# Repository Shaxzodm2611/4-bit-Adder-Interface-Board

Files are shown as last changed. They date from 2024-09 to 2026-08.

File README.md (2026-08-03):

# 4-bit Adder Interface Board

> **AI-generated README**: This README was generated with AI from the repository contents and may contain mistakes or omissions. Please verify hardware details, part numbers, and wiring against the KiCad source files before using it as authoritative documentation.

## Overview

This repository contains KiCad design files for a custom PCB titled **4 Bit - Seven Seg Interface**. The project appears to be a discrete-logic interface board built around a 4-bit adder and related support circuitry, intended to drive or interface with a seven-segment display.

The repository description indicates it is:

> “A custom PCB designed to mimic the function of a CPU. Entirely made from discrete logic ICs.”

## What is in the repository

The project is organized as a KiCad hardware design with schematic sheets and board/layout files, including:

- **PCB layout**: `4 Bit - Seven Seg Interface.kicad_pcb`
- **KiCad project**: `4 Bit - Seven Seg Interface.kicad_pro`
- **Main schematic**: `4 Bit - Seven Seg Interface.kicad_sch`
- **Supporting schematics**:
  - `Adders.kicad_sch`
  - `Registers.kicad_sch`
  - `Decoder.kicad_sch`
  - `Hex.kicad_sch`
  - `A.kicad_sch`
  - `C&D.kicad_sch`
  - `G.kicad_sch`
  - `555Timer.kicad_sch`
  - `untitled.kicad_sch`
- **Footprint libraries**:
  - `Components.pretty/`
  - `15000LED.pretty/`
- **Backup files**:
  - `4 Bit - Seven Seg Interface-backups/`

## Project structure and inferred function

From the schematic names and symbols used in the design, the board likely includes:

- **4-bit adder stage** using a `CD74HC283M96` 4-bit binary adder
- **Register / storage logic** using flip-flops and DIP switch inputs
- **Decoder / inverter logic** for signal conditioning and display control
- **Seven-segment display interface** using an `LSHD-7503` display component
- **Clock/timing circuitry** using a `555Timer` schematic section
- **Discrete logic gates** such as AND, OR, and NOT devices from the SN74LVC and CD4000 families

## Notable components seen in the schematics

A few parts are visible in the schematic source:

- `CD74HC283M96` — 4-bit binary adder
- `SN74LVC1G08DBVR` — 2-input AND gate
- `SN74LVC1G11DBVR` — 3-input AND gate
- `SN74LVC1G32DCKR` — 2-input OR gate
- `SN74LVC1G14DCKR` — inverter / Schmitt trigger
- `SN74LVC1G175DCKR` — D flip-flop with async clear
- `CD4072BM96` — dual 4-input OR gate
- `LSHD-7503` — seven-segment display
- `CFS-0102TB` — DIP switch component
- `219-8MST` — switch component
- LEDs, resistors, and capacitors for support circuitry

## Likely purpose

Based on the file names and symbols, this board seems intended to:

- accept switch inputs
- store or route 4-bit values
- perform addition with a 4-bit adder
- decode or condition signals
- display results on a seven-segment display

## Getting started

To work with this repository:

1. Install a compatible version of **KiCad 8**.
2. Open `4 Bit - Seven Seg Interface.kicad_pro` in KiCad.
3. Inspect the schematic sheets and PCB layout.
4. Review footprints and part choices before fabrication.

## Manufacturing / fabrication notes

This repository appears to be a hardware design project, so you will likely need to:

- verify all footprints
- confirm net connectivity and board rules in KiCad
- generate Gerbers, drill files, and BOM from the project
- review backups and autosave files before committing to fabrication

## Caveats

Because this README was generated automatically:

- component roles may be inferred incorrectly
- sheet names may not perfectly describe their actual logic
- some file names may represent work-in-progress or unused sheets
- exact electrical behavior should be confirmed in KiCad

## License

No license file was found in the repository contents examined here. If you plan to reuse or distribute the design, check with the repository owner or add an explicit license.

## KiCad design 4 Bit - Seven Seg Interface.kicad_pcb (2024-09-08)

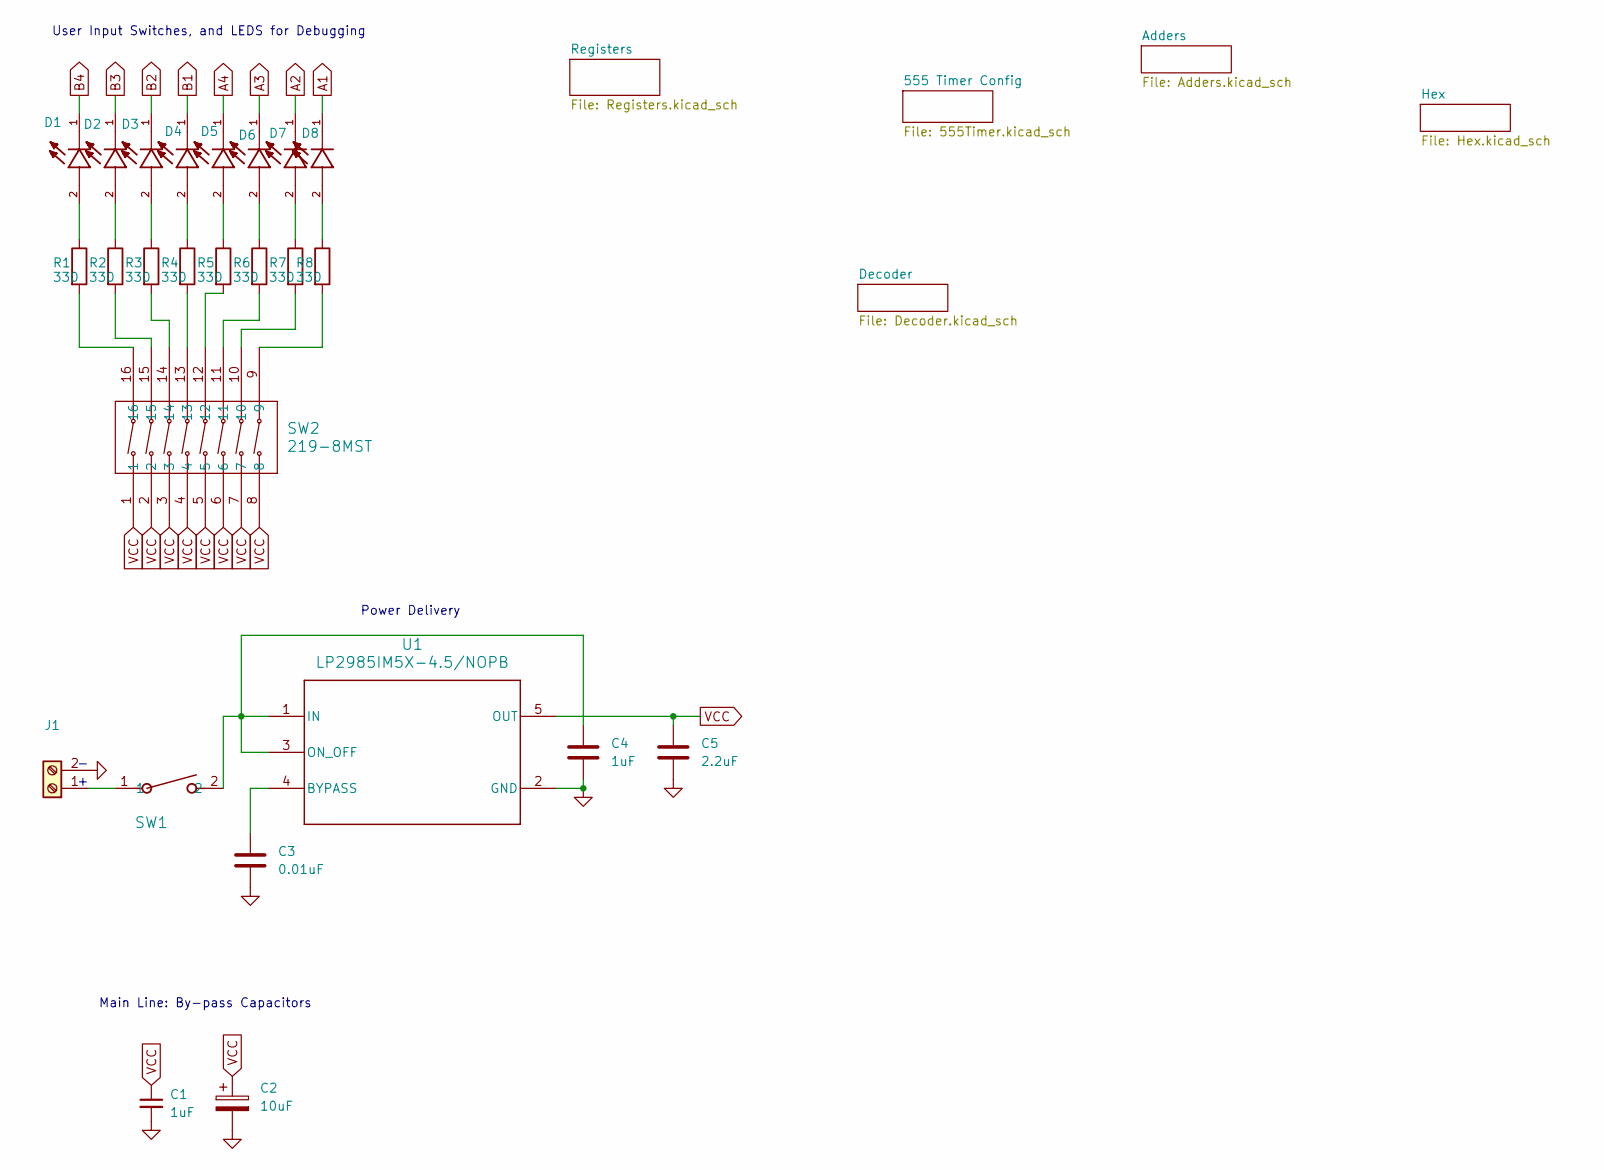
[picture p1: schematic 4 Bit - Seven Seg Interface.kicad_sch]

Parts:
C1, C4: 1uF; C_0603_1608Metric_Pad1.08x0.95mm_HandSolder
C2: 10uF; 10uF electrolytic Capacitor
C3: 0.01uF; C_0603_1608Metric_Pad1.08x0.95mm_HandSolder
C5: 2.2uF; C_0603_1608Metric_Pad1.08x0.95mm_HandSolder
D1, D2, D3, D4, D5, D6, D7, D8: 150060RS75000; LED_150060RS75000; PARTREV 2/26/2019
J1: Screw_Terminal_01x02; Screw-in Terminal
R1, R2, R3, R4, R5, R6, R7, R8: 330; R330-0805
SW1: CFS-0102TB; SW2_CFS-0102TB_NDC
SW2: 219-8MST; SO16_219-8_CTS
U1: LP2985IM5X-4.5/NOPB; DBV0005A_N (16v - 4.5 v VREG)com

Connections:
A1: D8.1; also elsewhere on the board
A2: D7.1; also elsewhere on the board
A3: D6.1; also elsewhere on the board
A4: D5.1; also elsewhere on the board
B1: D4.1; also elsewhere on the board
B2: D3.1; also elsewhere on the board
B3: D2.1; also elsewhere on the board
B4: D1.1; also elsewhere on the board
GND: C1.2, C2.2, C3.2, C4.2, C5.2, J1.2, U1.2 (GND); also elsewhere on the board
unnamed: D1.2, R1.1
unnamed: D2.2, R2.1
unnamed: D3.2, R3.1
unnamed: D4.2, R4.1
unnamed: D5.2, R5.1
unnamed: D6.2, R6.1
unnamed: D7.2, R7.1
unnamed: D8.2, R8.1
unnamed 29: J1.1, SW1.1; also elsewhere on the board
unnamed: R1.2, SW2.16
unnamed: R2.2, SW2.15
unnamed: R3.2, SW2.14
unnamed: R4.2, SW2.13
unnamed: R5.2, SW2.12
unnamed: R6.2, SW2.11
unnamed: R7.2, SW2.10
unnamed: R8.2, SW2.9
unnamed: C3.1, U1.4 (BYPASS)
unnamed 39: C4.1, SW1.2, U1.1 (IN), U1.3 (ON_OFF); also elsewhere on the board
VCC: C1.1, C2.1, C5.1, SW2.1, SW2.2, SW2.3, SW2.4, SW2.5, SW2.6, SW2.7, SW2.8, U1.5 (OUT); also elsewhere on the board

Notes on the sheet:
Power Delivery
Main Line: By-pass Capacitors
User Input Switches, and LEDS for Debugging

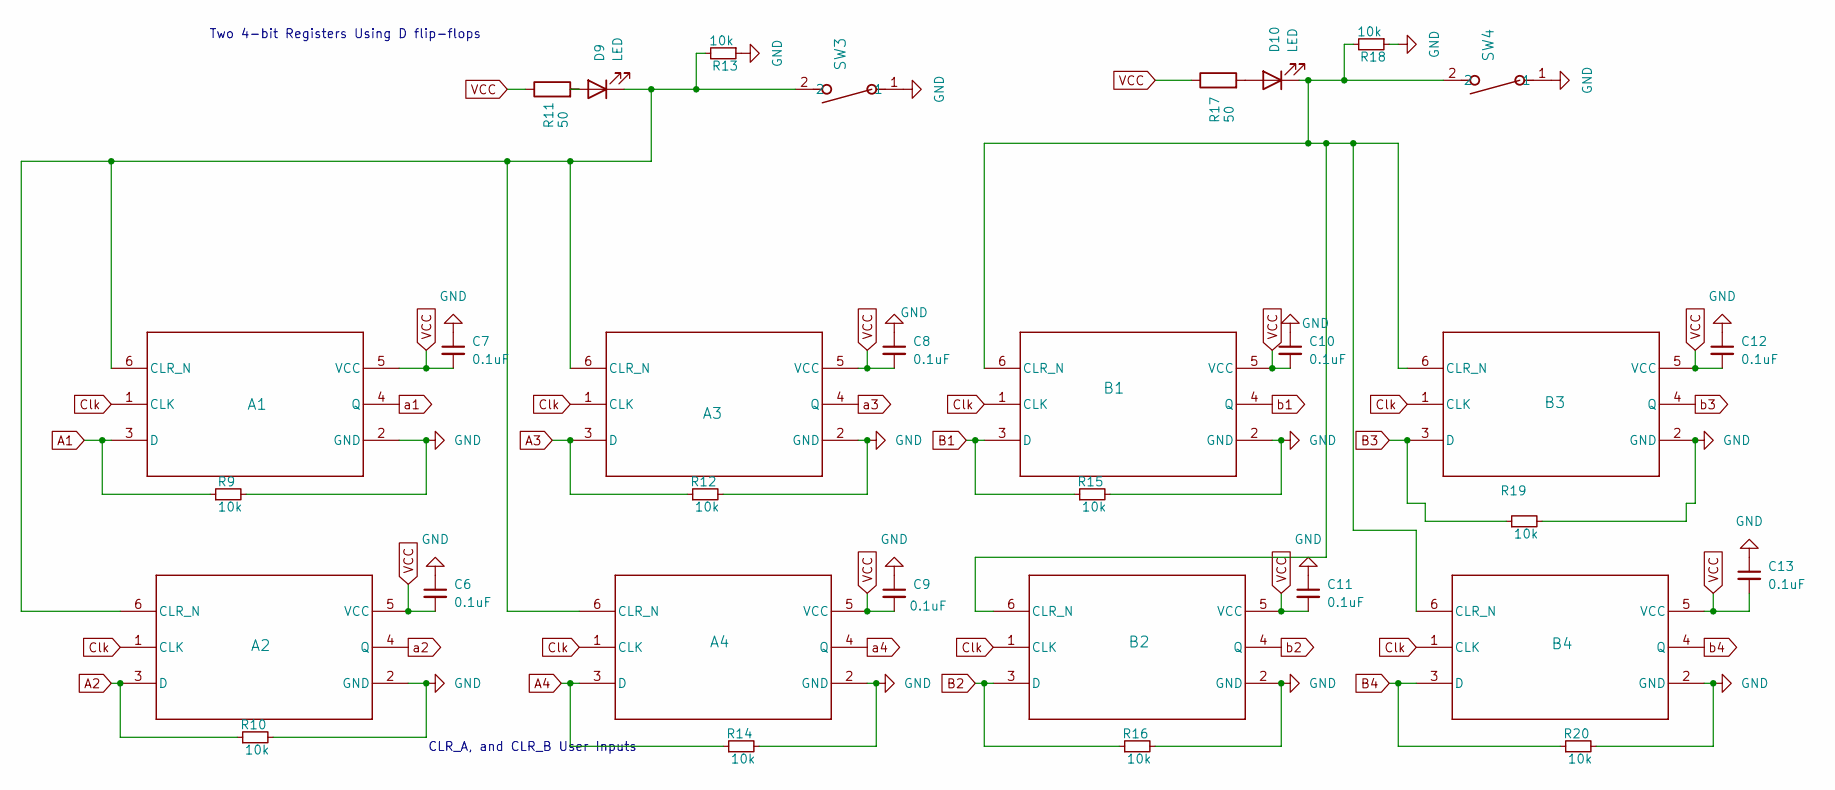
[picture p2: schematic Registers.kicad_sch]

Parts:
A1, A2, A3, A4: SN74LVC1G175DCKR; DCK0006A_N
B1, B2, B3, B4: SN74LVC1G175DCKR; DCK0006A_N
C6, C7, C8, C9, C10, C11, C12, C13: 0.1uF; 0603-0.1uF
D9, D10: LED; GLED0805
R9, R10, R12, R13, R14, R15, R16, R18, R19, R20: 10k; R805-10k
R11, R17: 50; 0603R-50ohms
SW3, SW4: CFS-0102TB; SW2_CFS-0102TB_NDC

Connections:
A1: A1.3 (D), R9.1; also elsewhere on the board
A2: A2.3 (D), R10.1; also elsewhere on the board
A3: A3.3 (D), R12.1; also elsewhere on the board
A4: A4.3 (D), R14.1; also elsewhere on the board
B1: B1.3 (D), R15.1; also elsewhere on the board
B2: B2.3 (D), R16.1; also elsewhere on the board
B3: B3.3 (D), R19.1; also elsewhere on the board
B4: B4.3 (D), R20.1; also elsewhere on the board
Clk: A1.1 (CLK), A2.1 (CLK), A3.1 (CLK), A4.1 (CLK), B1.1 (CLK), B2.1 (CLK), B3.1 (CLK), B4.1 (CLK); also elsewhere on the board
GND: A1.2 (GND), A2.2 (GND), A3.2 (GND), A4.2 (GND), B1.2 (GND), B2.2 (GND), B3.2 (GND), B4.2 (GND), C6.1, C7.1, C8.1, C9.1, C10.1, C11.1, C12.1, C13.1, R9.2, R10.2, R12.2, R13.1, R14.2, R15.2, R16.2, R18.1, R19.2, R20.2, SW3.1, SW4.1; also elsewhere on the board
unnamed: A1.6 (CLR_N), A2.6 (CLR_N), A3.6 (CLR_N), A4.6 (CLR_N), D9.1 (K), R13.2, SW3.2
unnamed: B1.6 (CLR_N), B2.6 (CLR_N), B3.6 (CLR_N), B4.6 (CLR_N), D10.1 (K), R18.2, SW4.2
unnamed: D9.2 (A), R11.2
unnamed: D10.2 (A), R17.2
VCC: A1.5 (VCC), A2.5 (VCC), A3.5 (VCC), A4.5 (VCC), B1.5 (VCC), B2.5 (VCC), B3.5 (VCC), B4.5 (VCC), C6.2, C7.2, C8.2, C9.2, C10.2, C11.2, C12.2, C13.2, R11.1, R17.1; also elsewhere on the board
a1: A1.4 (Q); also elsewhere on the board
a2: A2.4 (Q); also elsewhere on the board
a3: A3.4 (Q); also elsewhere on the board
a4: A4.4 (Q); also elsewhere on the board
b1: B1.4 (Q); also elsewhere on the board
b2: B2.4 (Q); also elsewhere on the board
b3: B3.4 (Q); also elsewhere on the board
b4: B4.4 (Q); also elsewhere on the board

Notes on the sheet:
CLR_A, and CLR_B User Inputs
Two 4-bit Registers Using D flip-flops

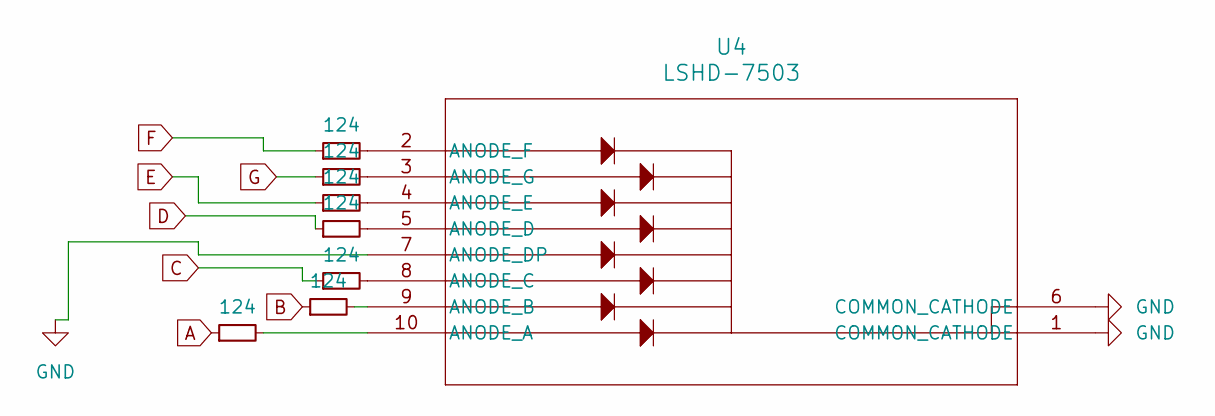
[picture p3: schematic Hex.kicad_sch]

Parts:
R23, R24, R25, R26, R27, R28, R29: 124; R_0603_1608Metric
U4: LSHD-7503; DIP10_LSHD-7503_LTO

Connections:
A: R23.1; also elsewhere on the board
B: R24.1; also elsewhere on the board
C: R29.1; also elsewhere on the board
D: R28.1; also elsewhere on the board
E: R27.1; also elsewhere on the board
F: R25.1; also elsewhere on the board
G: R26.1; also elsewhere on the board
GND: U4.1 (COMMON_CATHODE), U4.6 (COMMON_CATHODE), U4.7 (ANODE_DP); also elsewhere on the board
unnamed: R23.2, U4.10 (ANODE_A)
unnamed: R24.2, U4.9 (ANODE_B)
unnamed: R29.2, U4.8 (ANODE_C)
unnamed: R28.2, U4.5 (ANODE_D)
unnamed: R27.2, U4.4 (ANODE_E)
unnamed: R25.2, U4.2 (ANODE_F)
unnamed: R26.2, U4.3 (ANODE_G)

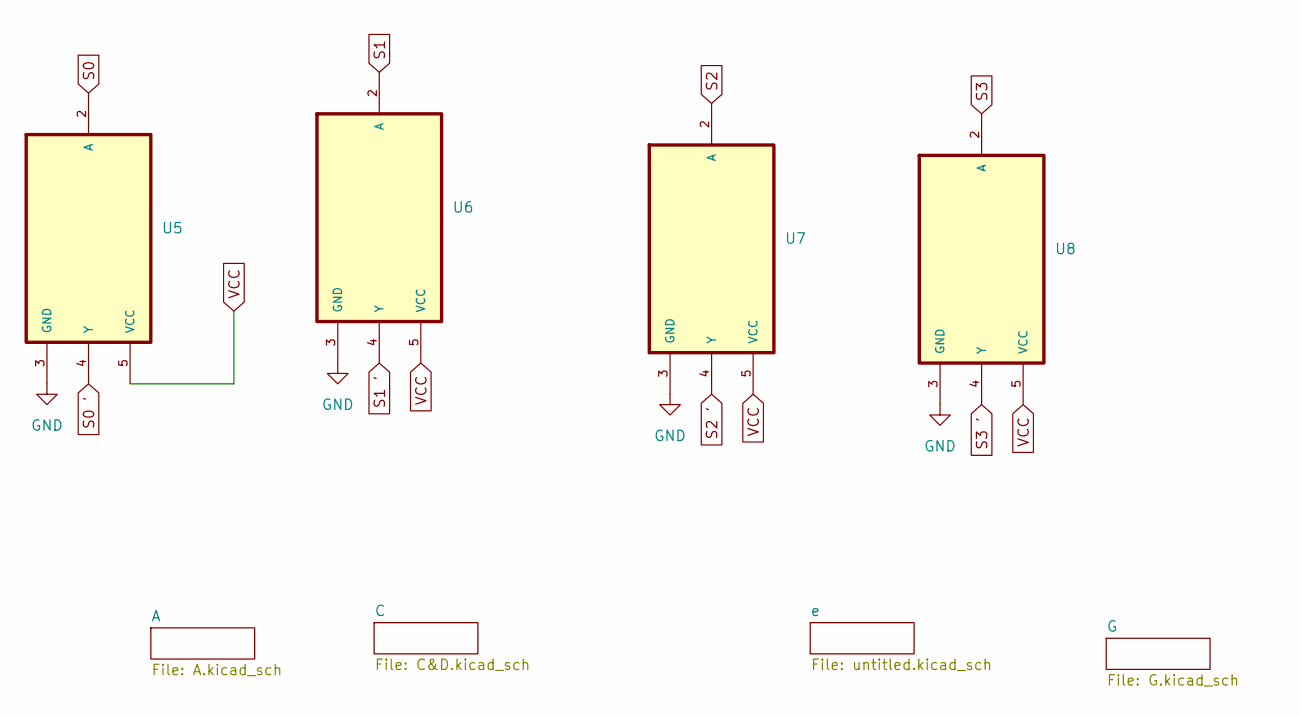
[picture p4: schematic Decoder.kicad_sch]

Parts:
U5, U6, U7, U8: SN74LVC1G14DCKR; 1INPUT_NOTGATE

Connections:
GND: U5.3 (GND), U6.3 (GND), U7.3 (GND), U8.3 (GND); also elsewhere on the board
S0: U5.2 (A); also elsewhere on the board
S0 ': U5.4 (Y); also elsewhere on the board
S1: U6.2 (A); also elsewhere on the board
S1 ': U6.4 (Y); also elsewhere on the board
S2: U7.2 (A); also elsewhere on the board
S2 ': U7.4 (Y); also elsewhere on the board
S3: U8.2 (A); also elsewhere on the board
S3 ': U8.4 (Y); also elsewhere on the board
VCC: U5.5 (VCC), U6.5 (VCC), U7.5 (VCC), U8.5 (VCC); also elsewhere on the board

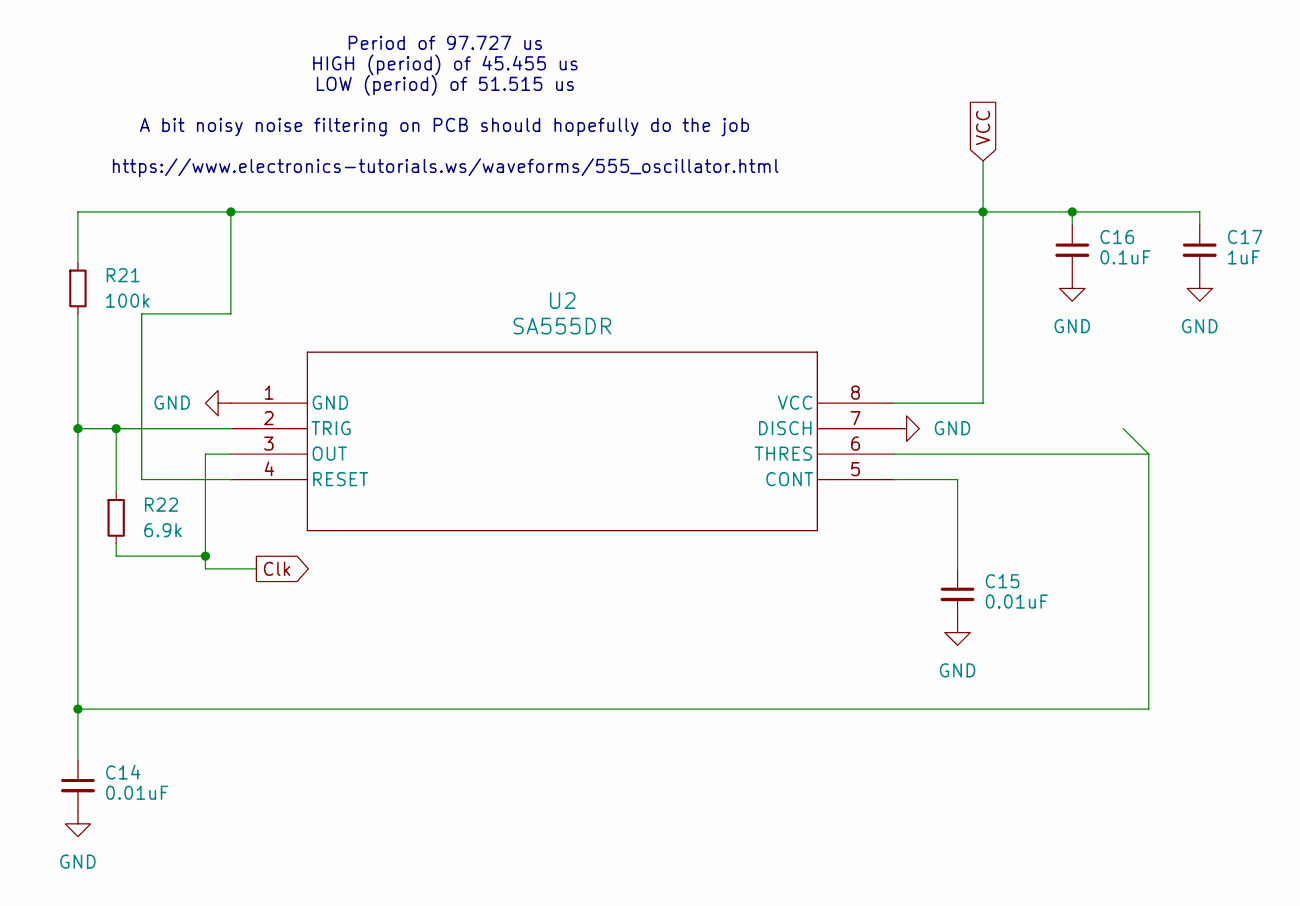
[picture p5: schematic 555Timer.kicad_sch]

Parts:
C14, C15: 0.01uF; C_0603_1608Metric_Pad1.08x0.95mm_HandSolder
C16: 0.1uF; C_0603_1608Metric_Pad1.08x0.95mm_HandSolder
C17: 1uF; C_0603_1608Metric_Pad1.08x0.95mm_HandSolder
R21: 100k; R_0603_1608Metric
R22: 6.9k; R_0603_1608Metric
U2: SA555DR; D8

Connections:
Clk: R22.2, U2.3 (OUT); also elsewhere on the board
GND: C14.2, C15.2, C16.2, C17.2, U2.1 (GND), U2.7 (DISCH); also elsewhere on the board
unnamed: C15.1, U2.5 (CONT)
unnamed: C14.1, R21.2, R22.1, U2.2 (TRIG), U2.6 (THRES)
VCC: C16.1, C17.1, R21.1, U2.4 (RESET), U2.8 (VCC); also elsewhere on the board

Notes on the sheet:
Period of 97.727 us HIGH (period) of 45.455 us LOW (period) of 51.515 us A bit noisy noise filtering on PCB should hopefully do the job https://www.electronics-tutorials.ws/waveforms/555_oscillator.html

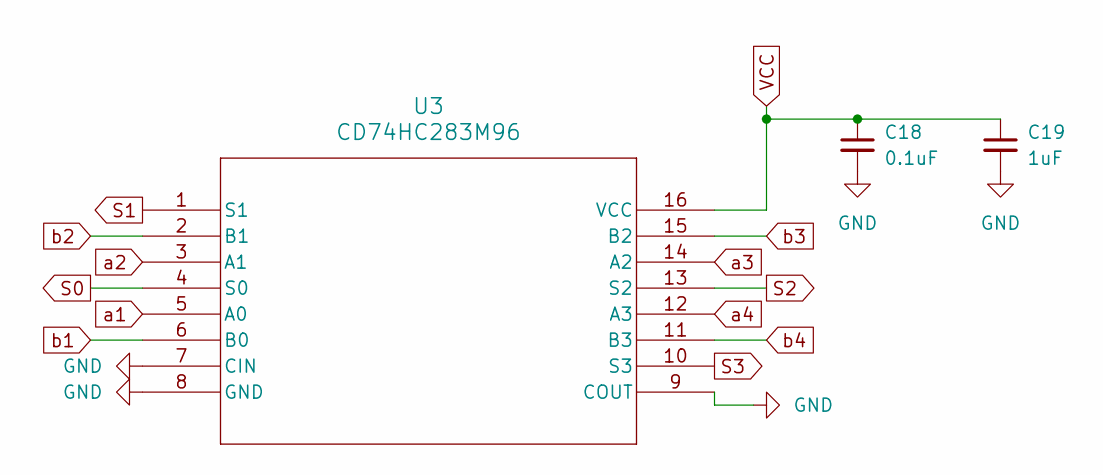
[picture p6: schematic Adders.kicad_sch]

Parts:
C18: 0.1uF; C_0603_1608Metric
C19: 1uF; C_0603_1608Metric
U3: CD74HC283M96; CD74HC283M96 (4-bit Binary Adder)

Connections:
GND: C18.2, C19.2, U3.7 (CIN), U3.8 (GND), U3.9 (COUT); also elsewhere on the board
S0: U3.4 (S0); also elsewhere on the board
S1: U3.1 (S1); also elsewhere on the board
S2: U3.13 (S2); also elsewhere on the board
S3: U3.10 (S3); also elsewhere on the board
VCC: C18.1, C19.1, U3.16 (VCC); also elsewhere on the board
a1: U3.5 (A0); also elsewhere on the board
a2: U3.3 (A1); also elsewhere on the board
a3: U3.14 (A2); also elsewhere on the board
a4: U3.12 (A3); also elsewhere on the board
b1: U3.6 (B0); also elsewhere on the board
b2: U3.2 (B1); also elsewhere on the board
b3: U3.15 (B2); also elsewhere on the board
b4: U3.11 (B3); also elsewhere on the board

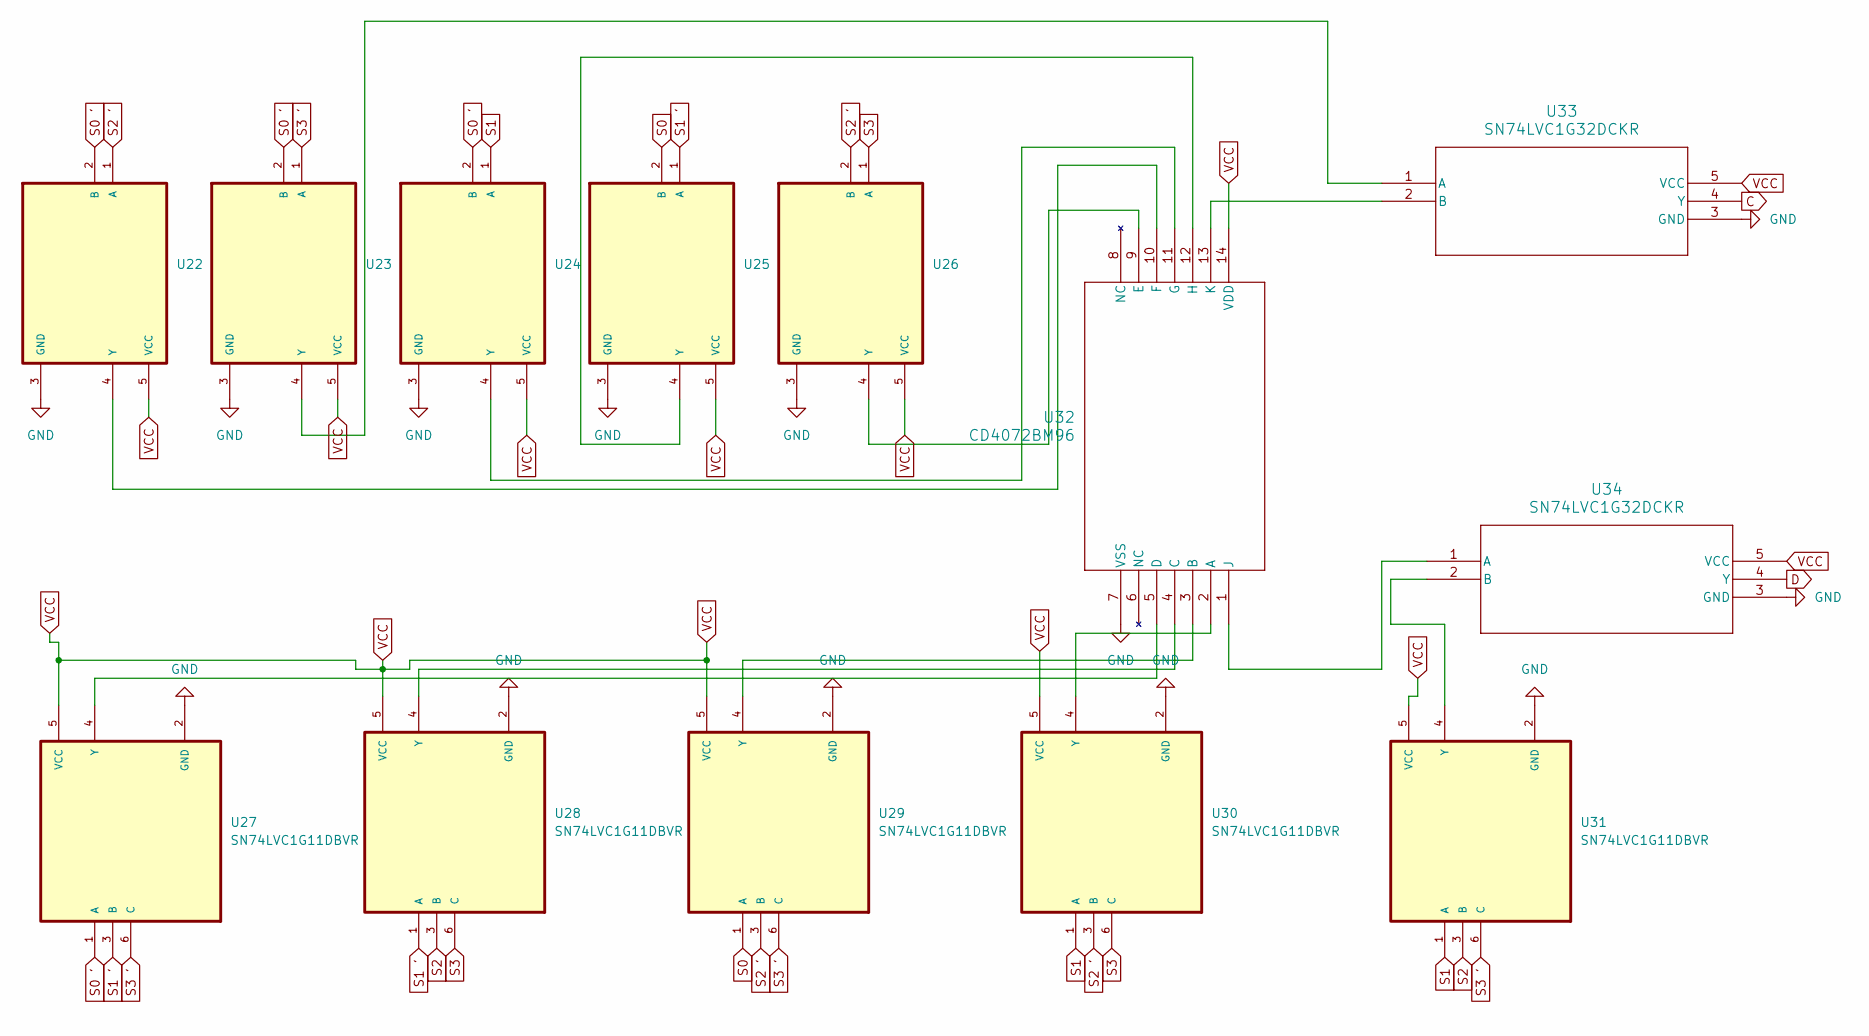
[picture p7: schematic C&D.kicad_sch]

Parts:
U22, U23, U24, U25, U26: SN74LVC1G08DBVR; SOT95P280X145-5N
U27, U28, U29, U30, U31: SN74LVC1G11DBVR; 3-INPUT AND
U32: CD4072BM96; 4-INPUT 2-CHN OR
U33, U34: SN74LVC1G32DCKR; 2-INPUT OR

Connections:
C: U33.4 (Y); also elsewhere on the board
D: U34.4 (Y); also elsewhere on the board
GND: U22.3 (GND), U23.3 (GND), U24.3 (GND), U25.3 (GND), U26.3 (GND), U27.2 (GND), U28.2 (GND), U29.2 (GND), U30.2 (GND), U31.2 (GND), U32.7 (VSS), U33.3 (GND), U34.3 (GND); also elsewhere on the board
unnamed: U22.4 (Y), U32.10 (F)
unnamed: U23.4 (Y), U33.1 (A)
unnamed: U24.4 (Y), U32.11 (G)
unnamed: U25.4 (Y), U32.12 (H)
unnamed: U26.4 (Y), U32.9 (E)
unnamed: U27.4 (Y), U32.5 (D)
unnamed: U28.4 (Y), U32.4 (C)
unnamed: U29.4 (Y), U32.3 (B)
unnamed: U30.4 (Y), U32.2 (A)
unnamed: U31.4 (Y), U34.2 (B)
unnamed: U32.1 (J), U34.1 (A)
unnamed: U32.13 (K), U33.2 (B)
S0: U25.2 (B), U29.1 (A); also elsewhere on the board
S0 ': U22.2 (B), U23.2 (B), U24.2 (B), U27.1 (A); also elsewhere on the board
S1: U24.1 (A), U30.1 (A), U31.1 (A); also elsewhere on the board
S1 ': U25.1 (A), U27.3 (B), U28.1 (A); also elsewhere on the board
S2: U28.3 (B), U31.3 (B); also elsewhere on the board
S2 ': U22.1 (A), U26.2 (B), U29.3 (B), U30.3 (B); also elsewhere on the board
S3: U26.1 (A), U28.6 (C), U30.6 (C); also elsewhere on the board
S3 ': U23.1 (A), U27.6 (C), U29.6 (C), U31.6 (C); also elsewhere on the board
VCC: U22.5 (VCC), U23.5 (VCC), U24.5 (VCC), U25.5 (VCC), U26.5 (VCC), U27.5 (VCC), U28.5 (VCC), U29.5 (VCC), U30.5 (VCC), U31.5 (VCC), U32.14 (VDD), U33.5 (VCC), U34.5 (VCC); also elsewhere on the board

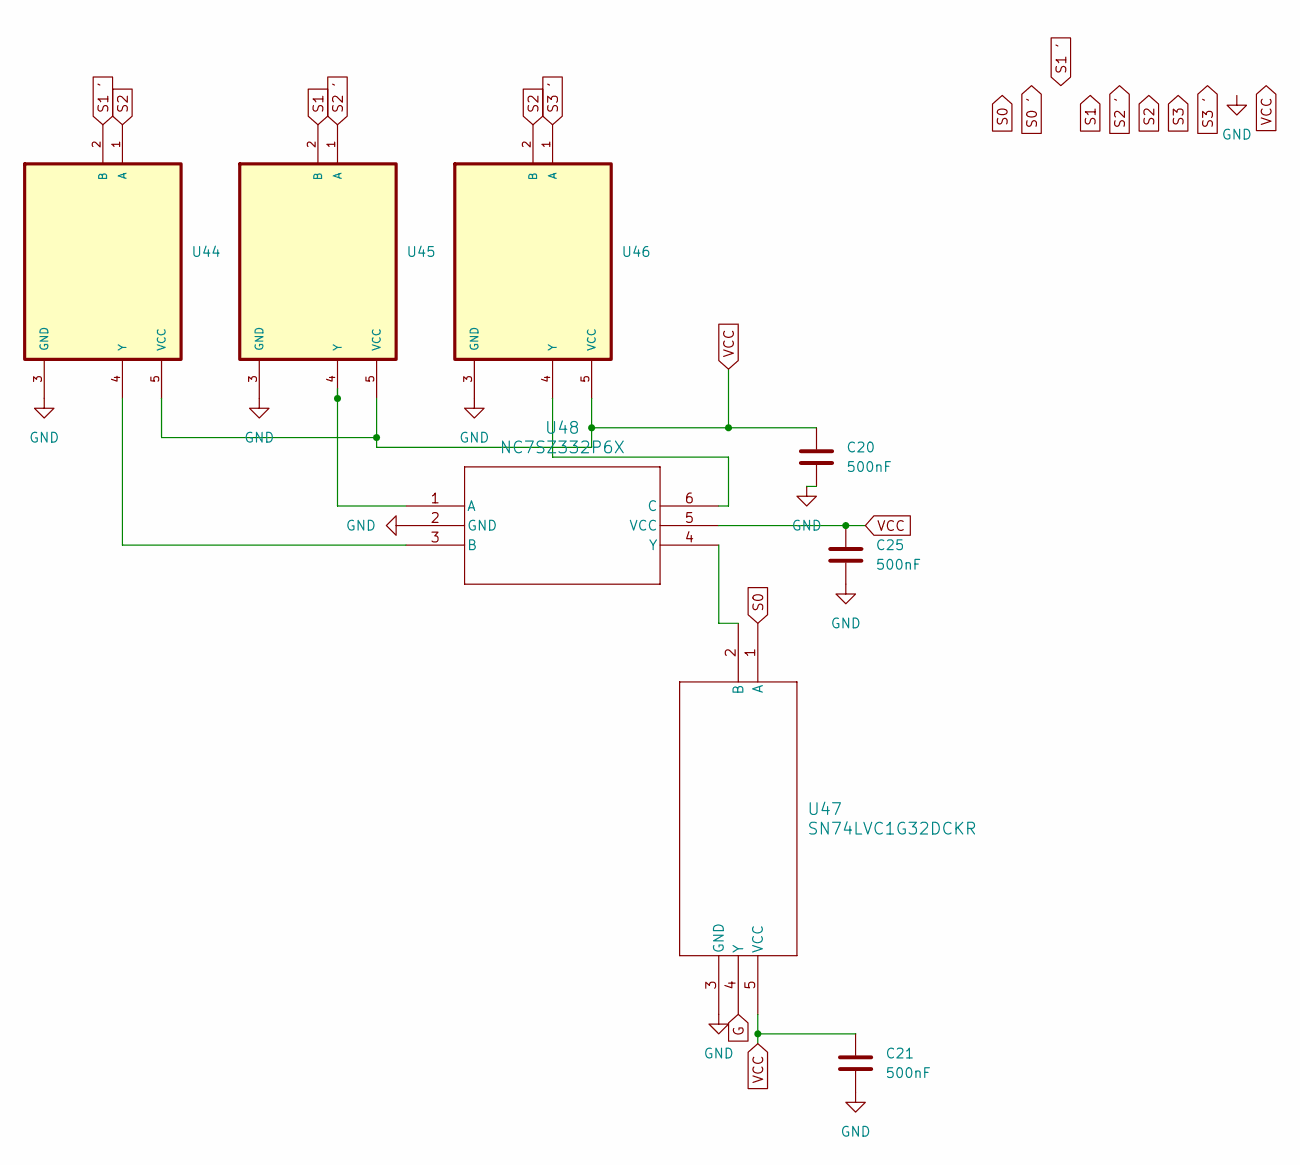
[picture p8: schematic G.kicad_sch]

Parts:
C20, C21, C25: 500nF; C_0603_1608Metric_Pad1.08x0.95mm_HandSolder
U44, U45, U46: SN74LVC1G08DBVR; SOT95P280X145-5N
U47: SN74LVC1G32DCKR; 2-INPUT OR
U48: NC7SZ332P6X; 3-INPUT OR

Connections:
G: U47.4 (Y); also elsewhere on the board
GND: C20.1, C21.1, C25.1, U44.3 (GND), U45.3 (GND), U46.3 (GND), U47.3 (GND), U48.2 (GND); also elsewhere on the board
unnamed: U44.4 (Y), U48.3 (B)
unnamed: U45.4 (Y), U48.1 (A)
unnamed: U46.4 (Y), U48.6 (C)
unnamed: U47.2 (B), U48.4 (Y)
S0: U47.1 (A); also elsewhere on the board
S1: U45.2 (B); also elsewhere on the board
S1 ': U44.2 (B); also elsewhere on the board
S2: U44.1 (A), U46.2 (B); also elsewhere on the board
S2 ': U45.1 (A); also elsewhere on the board
S3 ': U46.1 (A); also elsewhere on the board
VCC: C20.2, C21.2, C25.2, U44.5 (VCC), U45.5 (VCC), U46.5 (VCC), U47.5 (VCC), U48.5 (VCC); also elsewhere on the board

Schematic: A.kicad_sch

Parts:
U9, U10, U16, U17, U18, U19: SN74LVC1G11DBVR; 3-INPUT AND
U11, U12, U13, U20: SN74LVC1G08DBVR; SOT95P280X145-5N
U14: CD4072BM96; 4-INPUT 2-CHN OR
U15, U21: SN74LVC1G32DCKR; 2-INPUT OR

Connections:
A: U15.4 (Y); also elsewhere on the board
B: U21.4 (Y); also elsewhere on the board
GND: U9.2 (GND), U10.2 (GND), U11.3 (GND), U12.3 (GND), U13.3 (GND), U14.7 (VSS), U15.3 (GND), U16.2 (GND), U17.2 (GND), U18.2 (GND), U19.2 (GND), U20.3 (GND), U21.3 (GND); also elsewhere on the board
unnamed: U10.4 (Y), U14.3 (B)
unnamed: U11.4 (Y), U14.2 (A)
unnamed: U12.4 (Y), U14.4 (C)
unnamed: U13.4 (Y), U15.1 (A)
unnamed: U9.4 (Y), U14.5 (D)
unnamed: U14.9 (E), U17.4 (Y)
unnamed: U14.10 (F), U19.4 (Y)
unnamed: U14.11 (G), U18.4 (Y)
unnamed: U14.12 (H), U16.4 (Y)
unnamed: U14.1 (J), U15.2 (B)
unnamed: U14.13 (K), U21.1 (A)
unnamed: U20.4 (Y), U21.2 (B)
S0: U10.1 (A), U18.1 (A), U19.3 (B); also elsewhere on the board
S0 ': U9.6 (C), U11.2 (B), U16.1 (A), U17.1 (A); also elsewhere on the board
S1: U9.3 (B), U13.1 (A); also elsewhere on the board
S1 ': U10.3 (B), U12.2 (B), U20.1 (A); also elsewhere on the board
S2: U11.1 (A), U13.2 (B), U17.3 (B), U19.6 (C); also elsewhere on the board
S2 ': U10.6 (C), U16.3 (B), U18.3 (B); also elsewhere on the board
S3: U9.1 (A), U17.6 (C), U18.6 (C); also elsewhere on the board
S3 ': U12.1 (A), U16.6 (C), U19.1 (A), U20.2 (B); also elsewhere on the board
VCC: U9.5 (VCC), U10.5 (VCC), U11.5 (VCC), U12.5 (VCC), U13.5 (VCC), U14.14 (VDD), U15.5 (VCC), U16.5 (VCC), U17.5 (VCC), U18.5 (VCC), U19.5 (VCC), U20.5 (VCC), U21.5 (VCC); also elsewhere on the board

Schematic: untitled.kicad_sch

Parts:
C22, C23, C24: 500nF; C_0603_1608Metric
U35, U36, U42: SN74LVC1G08DBVR; SOT95P280X145-5N
U37, U38, U39, U40, U41: SN74LVC1G11DBVR; 3-INPUT AND
U43: CD4072BM96; 4-INPUT 2-CHN OR

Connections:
E: U43.1 (J); also elsewhere on the board
F: U43.13 (K); also elsewhere on the board
GND: C22.2, C23.2, C24.2, U35.3 (GND), U36.3 (GND), U37.2 (GND), U38.2 (GND), U39.2 (GND), U40.2 (GND), U41.2 (GND), U42.3 (GND), U43.7 (VSS); also elsewhere on the board
unnamed: U35.4 (Y), U43.2 (A)
unnamed: U36.4 (Y), U43.3 (B)
unnamed: U37.4 (Y), U43.4 (C)
unnamed: U38.4 (Y), U43.5 (D)
unnamed: U39.4 (Y), U43.12 (H)
unnamed: U40.4 (Y), U43.11 (G)
unnamed: U41.4 (Y), U43.10 (F)
unnamed: U42.4 (Y), U43.9 (E)
S0: U37.3 (B), U38.6 (C), U42.1 (A); also elsewhere on the board
S0 ': U39.1 (A), U40.1 (A); also elsewhere on the board
S1: U38.1 (A), U40.6 (C), U41.1 (A); also elsewhere on the board
S1 ': U35.2 (B), U37.6 (C), U42.2 (B); also elsewhere on the board
S2: U36.2 (B), U37.1 (A), U41.3 (B); also elsewhere on the board
S2 ': U38.3 (B), U39.3 (B), U40.3 (B); also elsewhere on the board
S3 ': U35.1 (A), U36.1 (A), U39.6 (C), U41.6 (C); also elsewhere on the board
VCC: C22.1, C23.1, C24.1, U35.5 (VCC), U36.5 (VCC), U37.5 (VCC), U38.5 (VCC), U39.5 (VCC), U40.5 (VCC), U41.5 (VCC), U42.5 (VCC), U43.14 (VDD); also elsewhere on the board

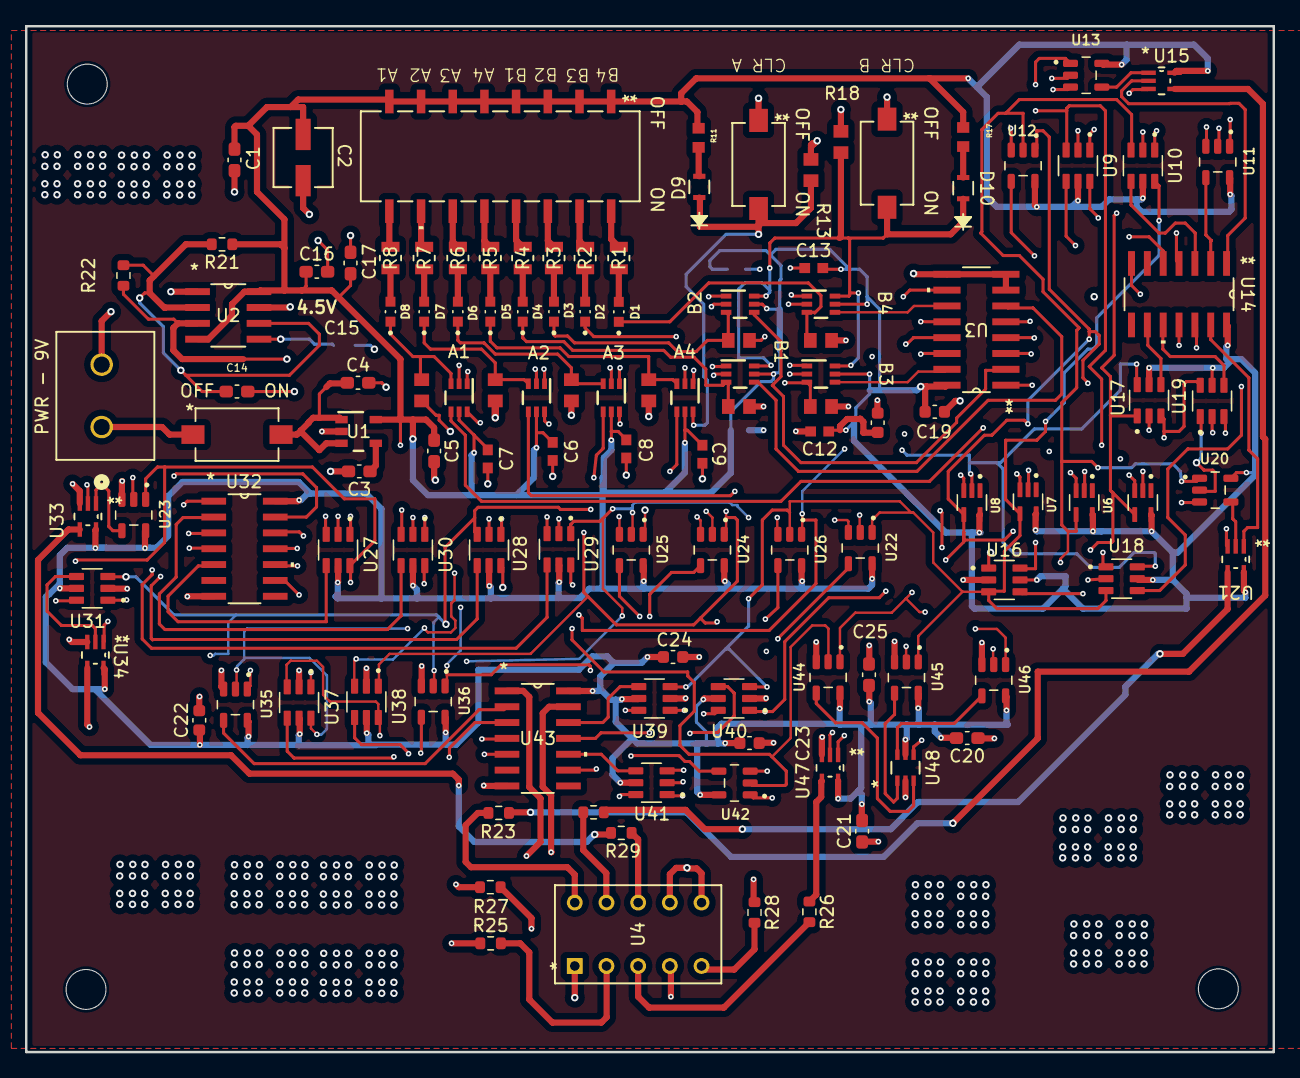
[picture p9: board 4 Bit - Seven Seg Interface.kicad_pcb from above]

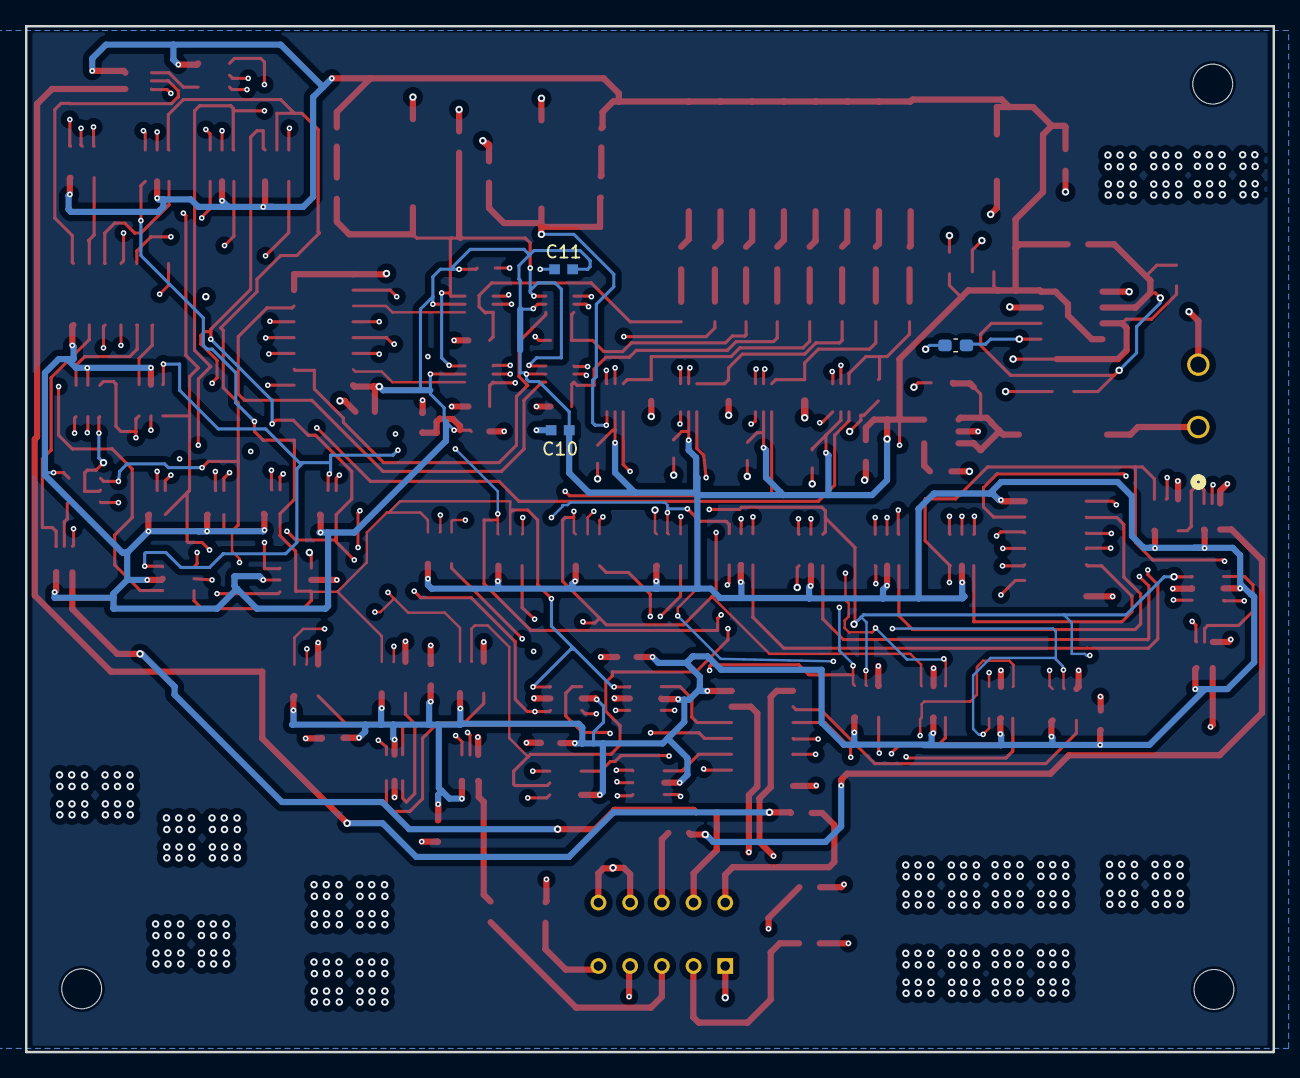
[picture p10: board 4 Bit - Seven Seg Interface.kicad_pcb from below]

Board: 4 copper layers, 100.0 x 82.2 mm, 125 parts (3 on the bottom side), 102 nets.

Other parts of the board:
PWR - 9V: CFS-0102TB; SW2_CFS-0102TB_NDC

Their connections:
unnamed 29: PWR - 9V.1; also elsewhere on the board
unnamed 39: PWR - 9V.2; also elsewhere on the board

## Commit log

2024-09-08 Add files via upload
    The raw ki-cad files for this project. As a note, this project currently does not function as intended, in the future, I intend to add a ADC so that the registers are able to read analog values. Furthermore, the reset pin on the D-Flips are not routed correctly, and the pull-high function in the circuit does not work as intended.
    [4 Bit - Seven Seg Interface.kicad_pcb, 4 Bit - Seven Seg Interface.kicad_sch, 555Timer.kicad_sch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]
2026-08-03 Add AI-generated README for KiCad 4-bit adder interface board project, with caveat note.
2026-08-03 Minimal KiCad-safe cleanup: rename backups/, remove lock file and cache, add .gitignore
